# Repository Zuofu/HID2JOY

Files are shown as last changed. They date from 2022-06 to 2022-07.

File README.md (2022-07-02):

# HID2JOY
## Xbox One Controller (and other USB) to Analog IBM PC Gameport Adapter
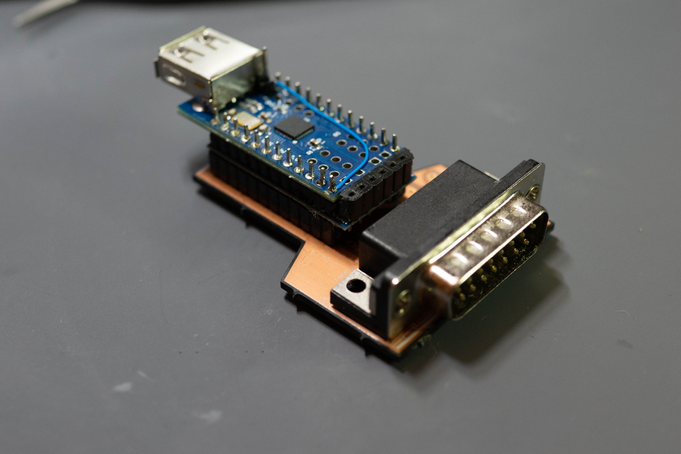
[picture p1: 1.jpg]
HID2JOY Assembled


### Intro
DOSBox has had the ability to map Xbox controllers to "Gameport" for a long time, but as far as I know, this is the first for people who want to use old hardware. I know of many converters that go the other way (use your old peripherals on a modern machine), but this allows you to use your nicer new controller with old machines. Anyway, this is WIP right now, and relies on Arduino, the USB Host Shield (MAX3421E) along with a Microchip DPot (actually, it's a rheostat). For now it only works with the Xbox One controller, since that's what the example code I started with is based off of, though it is trivial to extend to other supported controllers (Dualshock 3/4, Xbox 360..etc).

PCB is here: https://oshpark.com/projects/cPoLc5l8

### BOM:

1x Arduino Pro Mini or equivalent 3.3 V required - official or clones are fine, but make sure it's 3.3V

1x Mini USB Host Shield (based on MAX3421E) - find on eBay/Aliexpress/etc

1x MCP4452-104E digital rheostat (100K, quad channel, I2C)

2x 0603 4.7 kOhm resistor

1x 0603 .1uF ceramic capacitor

2x CES-112-01-T-S 12 position .1" pin header (low profile)

1x CES-102-02-T-S 2 position .1" pin header (low profile) or cut from larger part

1x ID15P33E4GV00LF or equivalent DB15 Male Connector right angle 2 row

Various .1" pin header strips

### Building and Modifications:

Cut trace here
You should cut the trace on the USB Host Shield between 3.3V and VUSB, and then wire a jumper from RAW to VUSB. This will allow the controller to work with 5V (as per the USB spec) and also bypass the already overloaded regulator on the Arduino. Otherwise assemble the base PCB, then solder the Mini Host Shield with the Arduino into a stack and then solder the stack to the base PCB. Program the Arduino with the code as follows (you will need some USB serial port). If you get build errors, make sure you've installed the USB Host Shield 2.0 library using the Arduino Library manager. Make sure you connect also connected A6/A7 used for I2C (these are the two connections not in the parallel headers) between the Arduino and the PCB.

### Additional Usage Instructions (subject to change):
Holding down VIEW for 3 seconds switches modes. Here are the currently supported modes:

Standard 4 axis 4 button (mode 1)
Triggers and Buttons overloaded to A/B/X/Y

Thrustmaster emulation (mode 2)
Triggers are used for analog rudder X2 (Left/Right relative). Y2 is used for POV hat, multiple simultanous button presses are allowed. Note, I don't know the correct resistance values, can someone who owns Thrustmaster measure?

CH Flightstick emulation (mode 3)
Triggers are used for analog rudder X2 (Left/Right relative), left stick is used for digital POV hat along with D-pad. Buttons chords are used for POV hat (digital) . Multiple simultanous button pressed not allowed.

CH Flightstick emulation alternate (mode 4)
Triggers are used for analog rudder X2 (Left/Right relative), left stick is used for throttle (up/down). Buttons chords are used for POV hat (digital) with D-pad. Multiple simultanous button pressed not allowed.

Current design remembers last mode using EEPROM and will power up with last used mode.

Holding down MENU for 3 seconds swaps behavior of left and right sticks.

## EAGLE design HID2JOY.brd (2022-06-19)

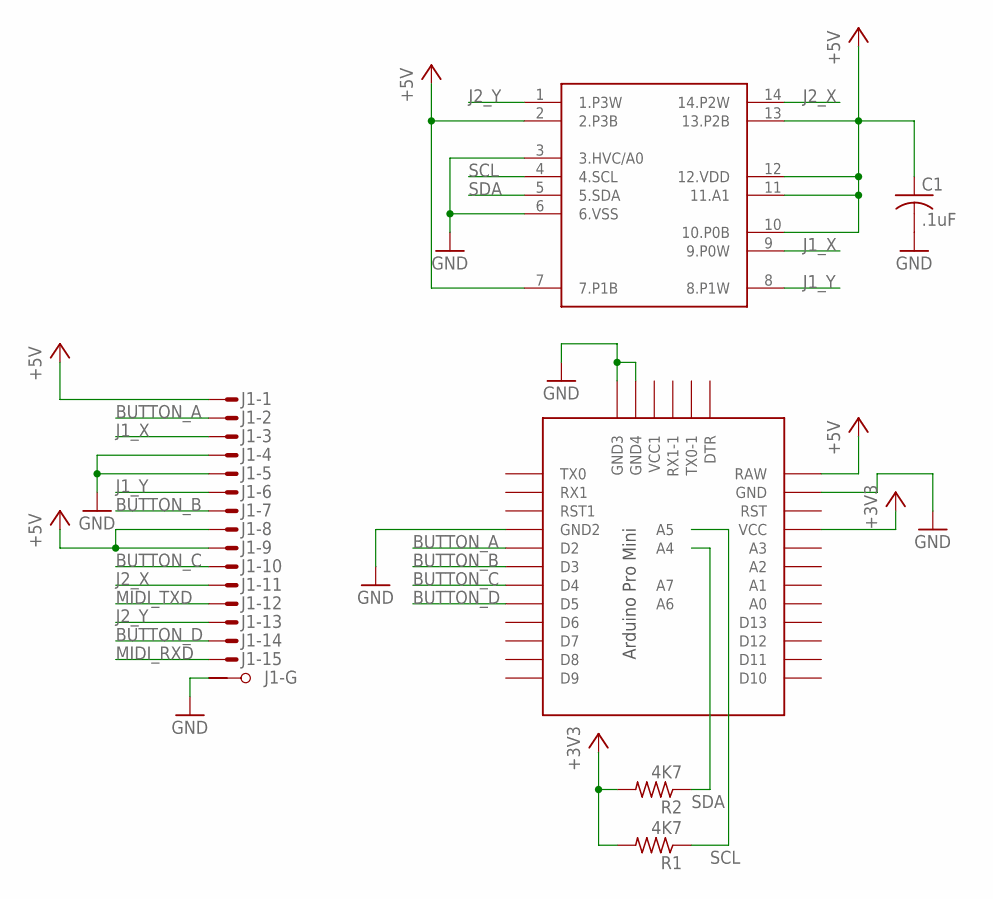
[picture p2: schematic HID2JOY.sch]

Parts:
C1: .1uF; C0603
J1: M15HPS; M15HP
R1, R2: 4K7; R0603
U1: PCM44X2TSSOP; TSSOP14
U$1: PRO-MINI-2

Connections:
+3V3: R1.2, R2.2, U$1.VCC
+5V: C1.1, J1.1 (M), J1.8 (M), J1.9 (M), U1.2 (2.P3B), U1.7 (7.P1B), U1.10 (10.P0B), U1.11 (11.A1), U1.12 (12.VDD), U1.13 (13.P2B), U$1.RAW
BUTTON_A: J1.2 (M), U$1.D2
BUTTON_B: J1.7 (M), U$1.D3
BUTTON_C: J1.10 (M), U$1.D4
BUTTON_D: J1.14 (M), U$1.D5
GND: C1.2, J1.4 (M), J1.5 (M), J1.G1, U1.3 (3.HVC/A0), U1.6 (6.VSS), U$1.GND, U$1.GND1 (GND2), U$1.GND2 (GND3), U$1.GND3 (GND4)
J1_X: J1.3 (M), U1.9 (9.P0W)
J1_Y: J1.6 (M), U1.8 (8.P1W)
J2_X: J1.11 (M), U1.14 (14.P2W)
J2_Y: J1.13 (M), U1.1 (1.P3W)
MIDI_RXD: J1.15 (M)
MIDI_TXD: J1.12 (M)
SCL: R1.1, U1.4 (4.SCL), U$1.A5
SDA: R2.1, U1.5 (5.SDA), U$1.A4

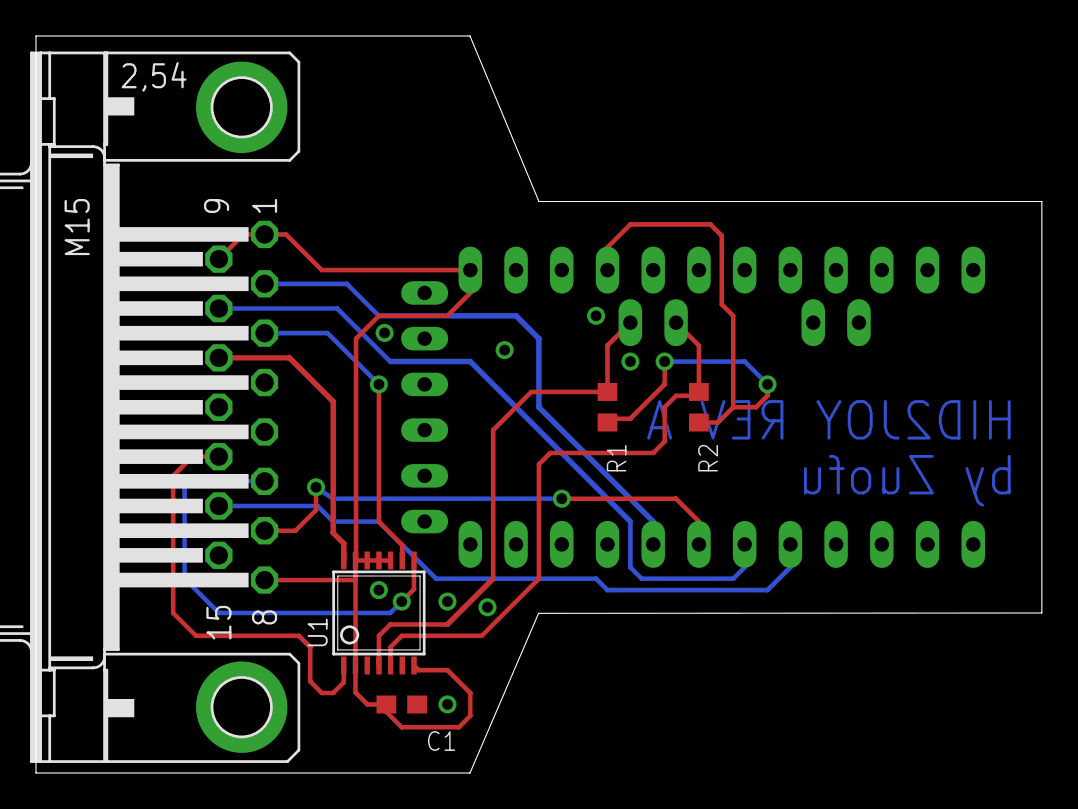
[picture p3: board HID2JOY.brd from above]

Board: 2 copper layers, 55.9 x 40.9 mm, 6 parts (0 on the bottom side), 13 nets.

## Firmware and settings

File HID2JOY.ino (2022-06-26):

//HID2JOY - Xbox One Controller (and other USB) to Analog IBM PC Gameport Adapter
//by Zuofu, requires USB Host Shield 2.0 Library
//Example sketch for the Xbox ONE USB library - by guruthree, based on work by
//Kristian Lauszus.

#include <XBOXONE.h>
#include <EEPROM.h>
#include <Wire.h>

// Satisfy the IDE, which needs to see the include statment in the ino too.
#ifdef dobogusinclude
#include <spi4teensy3.h>
#endif
#include <SPI.h>

#define JOY1_X         0
#define JOY1_Y         1
#define JOY2_X         2
#define JOY2_Y         3

#define DUAL_STICK          0
#define THRUSTMASTER        1
#define CH_FLIGHTSTICK_ALT  2
#define CH_FLIGHTSTICK      3

#define THROTTLE_SLEW  512  //larger number means slower throttle slew 

#define DPOT_I2C_ADDR  0x2E //modify if porting to a different DPOT
#define MODE_ROM_ADDR  0x00
#define SWAP_ROM_ADDR  0x01

#define PULSE_LONG     75
#define PULSE_SHORT    50

USB Usb;
XBOXONE Xbox(&Usb);

const byte      RegAddr[] = {0x00, 0x10, 0x60, 0x70}; //DPOT registers for 4 channels
AnalogHatEnum   hats[4] = {LeftHatX, LeftHatY, RightHatX, RightHatY};
byte            mode;
bool            swap;

void setAnalogJoy(int value, byte channel)
{ 
  Wire.beginTransmission(DPOT_I2C_ADDR);
  Wire.write(RegAddr[channel]);
  Wire.write(byte((value/256) + 128));
  Wire.endTransmission();
}

//pulse the controller rumble, useful for devices such as Xbox One which don't have programmable LEDs
void controllerPulse (byte times, int duration)
{
  for (byte i = 0; i < times; i++)
  {
    Xbox.setRumbleOn(128, 128, 64, 64);
    delay(duration);
    Xbox.setRumbleOff(); 
    delay(duration);
  }
}

void indicateMode (byte mode)
{
  //This can be made fancier later with (e.g.) colors on the PS4/PS5 controller
  
  switch (mode)
  {
    case DUAL_STICK:
      Serial.print(F("\r\nDual Stick Mode"));
      break;
    case THRUSTMASTER:
      Serial.print(F("\r\nThrustmaster Mode"));
      break;
    case CH_FLIGHTSTICK_ALT:
      Serial.print(F("\r\nCH Flightstick Mode (no analog throttle)"));
      break;
    case CH_FLIGHTSTICK:
      Serial.print(F("\r\nCH Flightstick Mode"));
      break;
  }
  controllerPulse (mode + 1, PULSE_SHORT);
}

void doSwap (bool swap)
{
  if (swap)
  {
    hats[0] = RightHatX;
    hats[1] = RightHatY; 
    hats[2] = LeftHatX;
    hats[3] = LeftHatY;
    Serial.print(F("\r\nSticks Swapped"));
  }
  else
  {
    hats[0] = LeftHatX;
    hats[1] = LeftHatY;
    hats[2] = RightHatX;
    hats[3] = RightHatY; 
    Serial.print(F("\r\nSticks Normal"));
  }
  controllerPulse (swap + 1, PULSE_LONG);    
}

bool detectLongPress(ButtonEnum b, unsigned long & buttonDownTime, byte & buttonDownPrev)
{
    if (Xbox.getButtonPress(b) && !buttonDownPrev) //button pressed down
    {
      buttonDownTime = millis(); //record time & set down flag
      buttonDownPrev = 1;
    }
    else if (!Xbox.getButtonPress(b) && buttonDownPrev) //button was previously pressed but now released
    {  
      buttonDownPrev = 0;
    }
    else if (Xbox.getButtonPress(b) && (millis() - buttonDownTime > 3000) ) //button pressed for > 3 seconds
    {
      buttonDownPrev = 0;
      return 1;
    }
    return 0;  
}

void setup() {
  Serial.begin(115200);
  while (!Serial); // Wait for serial port to connect - used on Leonardo, Teensy and other boards with built-in USB CDC serial connection
  if (Usb.Init() == -1) {
    Serial.print(F("\r\nOSC did not start - do you have a USB host shield connected?"));
    while (1); //halt
  }
  Serial.print(F("\r\nXBOX ONE USB Library Started"));

  Wire.begin();          //Initialize I2C
  Wire.setClock(400000); //Run I2C at 400KHz TODO:Figure out how to use fastest mode
  
  pinMode(2, OUTPUT);    //Configure GPIOs
  pinMode(3, OUTPUT);
  pinMode(4, OUTPUT);
  pinMode(5, OUTPUT);
  digitalWrite (2, LOW);
  digitalWrite (3, LOW);
  digitalWrite (4, LOW);
  digitalWrite (5, LOW);

  mode = EEPROM.read(MODE_ROM_ADDR);
  if (mode > CH_FLIGHTSTICK) //if not a valid mode
  {
    mode = DUAL_STICK;
    EEPROM.write(MODE_ROM_ADDR, mode); //write a default mode
  }
  indicateMode (mode);

  swap = EEPROM.read(SWAP_ROM_ADDR);
  if (swap > 1) //invalid swap value (probably fresh EEPROM will read as 0xFF
  { 
    swap = false;
    EEPROM.write(SWAP_ROM_ADDR, swap); //write a default swap (0)
  }
  doSwap(swap);
}

void loop() 
{
  Usb.Task();
  
  if (Xbox.XboxOneConnected)  //Don't do anything unless Xbox controller is connected
  {
    static signed long     throttleValue = 0;
    unsigned int           X2_val;
    byte                   buttonState[6] = {0, 0, 0, 0, 0, 0}; //holds button state to set in a single place, assume all are off for now

    static unsigned long   viewDownTime;
    static byte            viewDownPrev = 0;
    static unsigned long   menuDownTime;
    static byte            menuDownPrev = 0;

    //long press of VIEW = switch mode
    if (detectLongPress(VIEW, viewDownTime, viewDownPrev))
    {
      //modify the mode
      if (mode < CH_FLIGHTSTICK)
      mode ++;
      else
      mode = DUAL_STICK;
      
      indicateMode(mode);
      EEPROM.write(MODE_ROM_ADDR, mode); //write mode to EEPROM
    }
    
    //long press of MENU = swap sticks
    if (detectLongPress(MENU, menuDownTime, menuDownPrev))
    {
      swap = !swap;
      doSwap(swap);
      EEPROM.write(SWAP_ROM_ADDR, swap); //write swap to EEPROM
    }

    //Do some common button mapping
    buttonState[2] = Xbox.getButtonPress(A);
    buttonState[3] = Xbox.getButtonPress(B);
    buttonState[4] = Xbox.getButtonPress(X);
    buttonState[5] = Xbox.getButtonPress(Y);

    //Allow LB and RB to also turn on buttons, but not turn off (they will automatically go off) 
    if (Xbox.getButtonPress(RB))
      buttonState[2] = 1;
    if (Xbox.getButtonPress(LB))
      buttonState[3] = 1;

    //Handle mode specific behavior
    switch (mode)
    {
      case DUAL_STICK: 
        //Conventional dual stick mode
        
        //set stick values
        setAnalogJoy (Xbox.getAnalogHat(hats[0]), JOY1_X);
        setAnalogJoy (~Xbox.getAnalogHat(hats[1]), JOY1_Y);
        //Y axis is inverted from Xbox, use ~ instead of - to avoid 2's complement asymmetry 
        setAnalogJoy (Xbox.getAnalogHat(hats[2]), JOY2_X);     
        setAnalogJoy (~Xbox.getAnalogHat(hats[3]), JOY2_Y);     
  
        //triggers are just overloaded as buttons
        if (Xbox.getButtonPress(LT))
          buttonState[4] = 1;
        else
          buttonState[4] = 0;
    
        if (Xbox.getButtonPress(RT))
          buttonState[5] = 1;
        else
          buttonState[5] = 0;
      break;

      case THRUSTMASTER:
        //Thrustmaster, encode POV hat using 4th axis
        setAnalogJoy (Xbox.getAnalogHat(hats[2]), JOY1_X);
        setAnalogJoy (~Xbox.getAnalogHat(hats[3]), JOY1_Y);
        setAnalogJoy ((signed(Xbox.getButtonPress(RT)*32) - signed(Xbox.getButtonPress(LT)*32)), JOY2_X); //Used for rudder, convert 10->16 bit
        
        //Process POV hat
        if (Xbox.getButtonPress(LEFT))
        {
          setAnalogJoy(-6553, JOY2_Y);
        }
        else if (Xbox.getButtonPress(DOWN))
        {
          setAnalogJoy(-13107, JOY2_Y);
        }
        else if (Xbox.getButtonPress(RIGHT))
        {
          setAnalogJoy(-19659, JOY2_Y);
        }
        else if (Xbox.getButtonPress(UP))
        {
          setAnalogJoy(-26212, JOY2_Y);
        }
        else
        {
          setAnalogJoy(0, JOY2_Y);
        }
      break;

      case CH_FLIGHTSTICK: //CH Flightstick with analog throttle
        //CH Flightstick, encode POV hat as chords, use Y2 as throttle
        //set stick values
        setAnalogJoy (Xbox.getAnalogHat(hats[2]), JOY1_X);
        setAnalogJoy (~Xbox.getAnalogHat(hats[3]), JOY1_Y);
        setAnalogJoy ((signed(Xbox.getButtonPress(RT)*32) - signed(Xbox.getButtonPress(LT)*32)), JOY2_X); //Used for rudder, convert 10->16 bit
        //Keep track of throttle using triggers, make sure it doesn't overflow
        if (Xbox.getAnalogHat(hats[1]) > 10000 || Xbox.getAnalogHat(hats[1]) < -10000) //only change throttle if deadzone exceeded
        {
          throttleValue += ( signed(Xbox.getAnalogHat(hats[1])) / THROTTLE_SLEW); 
          if (throttleValue > 32767)
            throttleValue = 32767;
          if (throttleValue < -32768)
            throttleValue = -32768; 
          setAnalogJoy (~throttleValue, JOY2_Y);
        }
    
        if (Xbox.getButtonPress(RIGHT) || Xbox.getButtonPress(LEFT) || Xbox.getButtonPress(UP) || Xbox.getButtonPress(DOWN))
        {
          //If any HAT button pressed, clear previous button reads
           buttonState[2] = 0;
           buttonState[3] = 0;
           buttonState[4] = 0;
           buttonState[5] = 0;
        }
        if (Xbox.getButtonPress(RIGHT)) 
        {
           buttonState[2] = 1;
           buttonState[3] = 1;
           buttonState[5] = 1;
        }
        else if (Xbox.getButtonPress(LEFT))
        {
           buttonState[2] = 1;
           buttonState[3] = 1;
        }
        else if (Xbox.getButtonPress(UP))
        {
           buttonState[2] = 1;
           buttonState[3] = 1;
           buttonState[4] = 1;
           buttonState[5] = 1;
        }
        else if (Xbox.getButtonPress(DOWN))
        {
           buttonState[2] = 1;
           buttonState[3] = 1;
           buttonState[4] = 1;
        }
        break;

        case CH_FLIGHTSTICK_ALT: //CH flightstick w/o analog throttle, map other stick to POV Hat
        //set stick values
        setAnalogJoy (Xbox.getAnalogHat(hats[2]), JOY1_X);
        setAnalogJoy (~Xbox.getAnalogHat(hats[3]), JOY1_Y);
        setAnalogJoy ((signed(Xbox.getButtonPress(RT)*32) - signed(Xbox.getButtonPress(LT)*32)), JOY2_X); //Used for rudder, convert 10->16 bit
        
        if (Xbox.getAnalogHat(hats[0]) > 10000 || Xbox.getAnalogHat(hats[0]) < -10000 || ~Xbox.getAnalogHat(hats[1]) > 10000 || ~Xbox.getAnalogHat(hats[1]) < -10000)
        {
          //If any HAT button pressed, clear previous button reads
           buttonState[2] = 0;
           buttonState[3] = 0;
           buttonState[4] = 0;
           buttonState[5] = 0;
        }
        if (Xbox.getAnalogHat(hats[0]) > 10000) 
        {
           buttonState[2] = 1;
           buttonState[3] = 1;
           buttonState[5] = 1;
        }
        else if (Xbox.getAnalogHat(hats[0]) < -10000)
        {
           buttonState[2] = 1;
           buttonState[3] = 1;
        }
        else if (~Xbox.getAnalogHat(hats[1]) < -10000)
        {
           buttonState[2] = 1;
           buttonState[3] = 1;
           buttonState[4] = 1;
           buttonState[5] = 1;
        }
        else if (~Xbox.getAnalogHat(hats[1]) > 10000)
        {
           buttonState[2] = 1;
           buttonState[3] = 1;
           buttonState[4] = 1;
        }
        break;

    }
    
    //Send out button presses based on state
    for (int i = 2; i < 6; i++)
    {
      if(buttonState[i])
       pinMode (i, OUTPUT);
      else
       pinMode (i, INPUT);
    }
    
  }
}

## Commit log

2022-06-20 Added CH Flightstick and Thrustmaster emulation modes. Thrustmaster mode isn't quite working in Strike Commander yet.
2022-06-21 Modified Thrustmaster rudder behavior to be consistent with CH Flightstick. Also documented modes.
2022-06-26 Added functionality to swap joysticks, also added CH Flightstick with second stick mapped to hat (useful for games which don't support analog throttle).
    [HID2JOY.ino]
